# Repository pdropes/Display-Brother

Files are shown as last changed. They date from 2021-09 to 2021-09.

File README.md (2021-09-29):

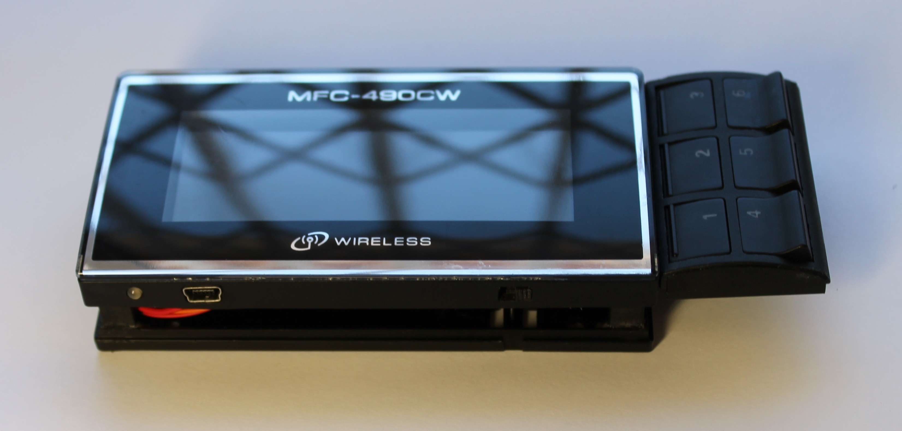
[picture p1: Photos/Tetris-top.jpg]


# Display-Brother
Reverse engineering a display

I had a brother printer, a color display and such, with a dismal flatcable communicating at a speed of +-4MHz... without a logic analyzer, it would be impossible to do anything to understand the protocol. Information on the net is non-existent, however the service manual is always better than nothing.
I got an AL for 200 bucks for this, I still use it.

It took me a long time to make this game, I didn't use any library and the code (Bascom AVR) is in a single file.
With the gathering of information, readings and tests, the files grew, ending up in 3,183 files.
After programming, 33 versions were needed, and now there are no apparent bugs.

These were the reasons why I haven't shared the code and other information yet (besides my pc having crashed), if I'm going to share something, I'd like it to make sense for those who are going to read it, and not a bunch of files.

Both the resolution and the quality reproduced on the display are low, however sufficient for many applications.

I started with an M8515 because it has more IOs, making it possible to connect to a PC's parallel port to exchange information.
All 120ohm resistors were soldered just as a precaution in the tests, there being no need to keep them after confirmation of communications.

The number of connections was reduced to a minimum, sometimes joining some, it was possible to connect it to a common m328 leaving 2 ADC pins available.

A lot of information about commercial displays and mobile phones circulates on the internet, I appreciate whoever recovers unused equipment for other purposes, this was one more challenge and a learning curve, since the expenses far exceed the value of a commercial display.

*Stay creative

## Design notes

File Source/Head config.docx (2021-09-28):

-Resumo das operações sugestivas a serem implementadas antes do envio de uma imagem-

'Contraste (valor de 0..3)

If Cnt = 85 Then

B2 = 0

End If

'Inversão de escrita (esquerda para direita)

If Cnt = 29 Then

B1 = 46

B2 = 34

End If

'Cores invertidas (apenas ao escrever)

If Cnt = 29 Then

B1 = 30

B2 = 18

End If

'Escreve apenas na selecção (valor de 0..175):

'Inicio da secção

If Cnt = 94 Then

B1 = 0

B2 = 0

End If

'Final da secção

If Cnt = 96 Then

B1 = 175

B2 = 175

End If

*_Cnt é um contador da posição da matriz de dados

*_B1 quadro 1

*_B2 quadro 2

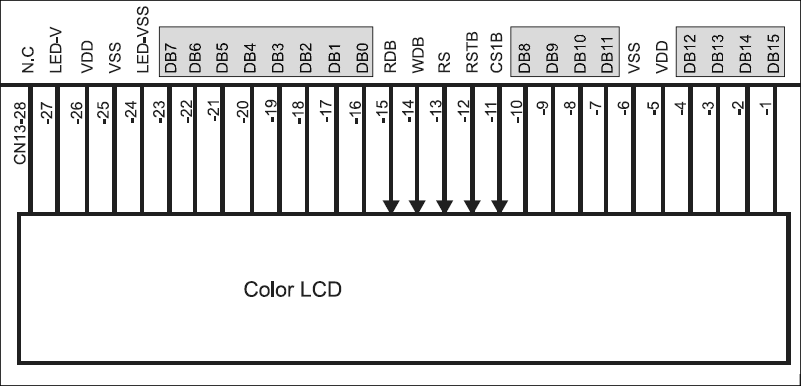
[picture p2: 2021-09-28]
Infos/Pinout Display 990CW.png

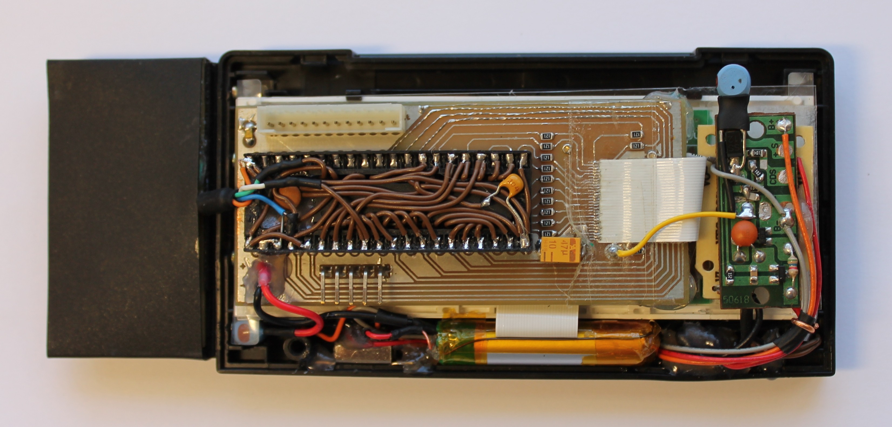
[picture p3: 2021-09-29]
Photos/Tetris-bottom.jpg

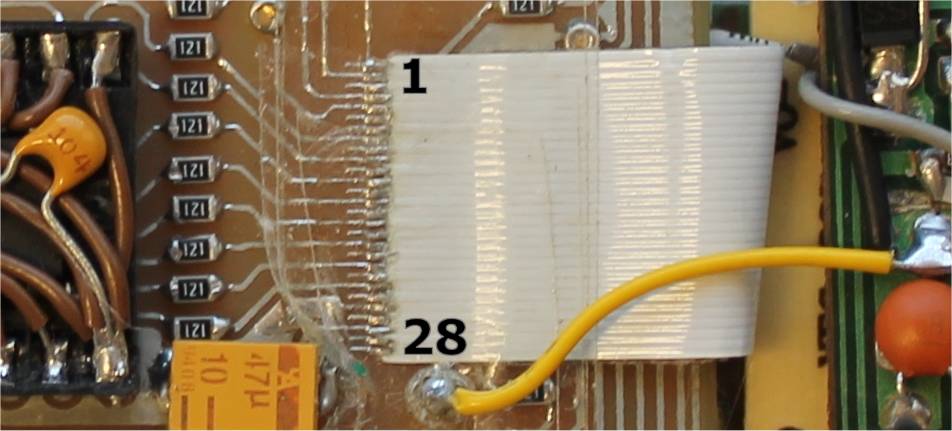
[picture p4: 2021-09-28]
Infos/Display Brother - orientação.jpg

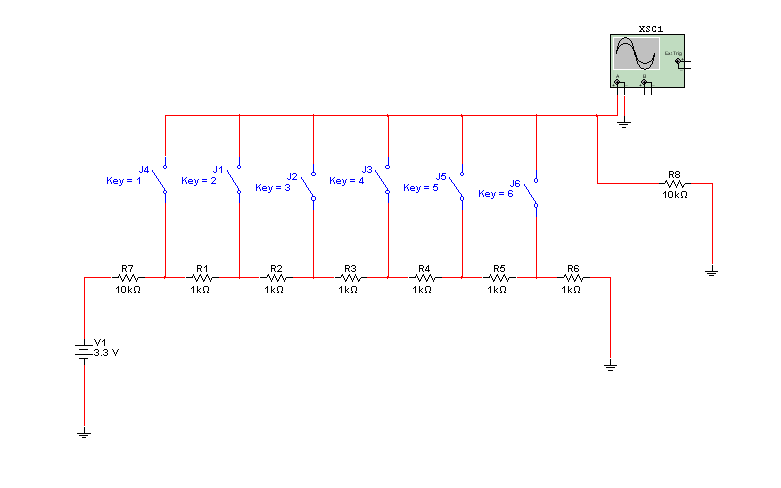
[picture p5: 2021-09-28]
Layout/switchs 6P 1Vmax.png

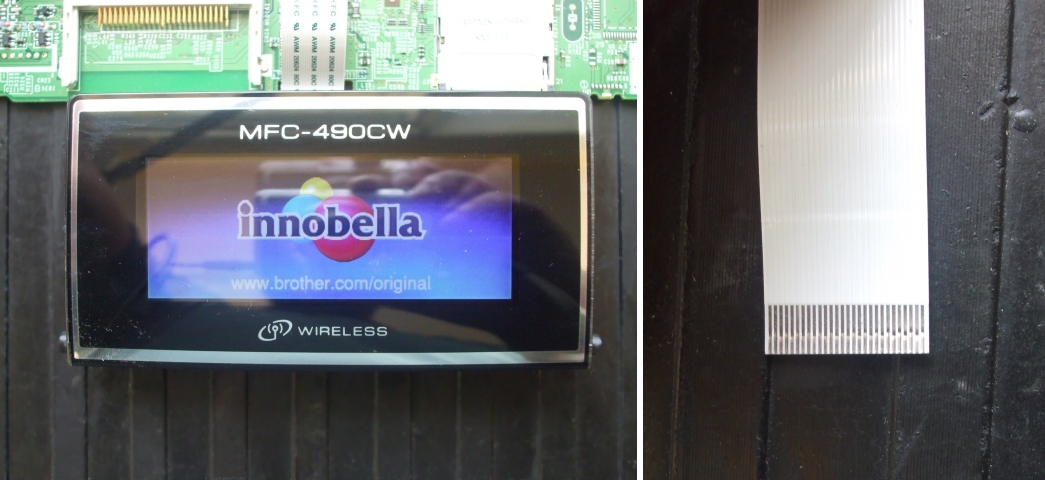
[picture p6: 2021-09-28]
Infos/Brother display + cable.jpg

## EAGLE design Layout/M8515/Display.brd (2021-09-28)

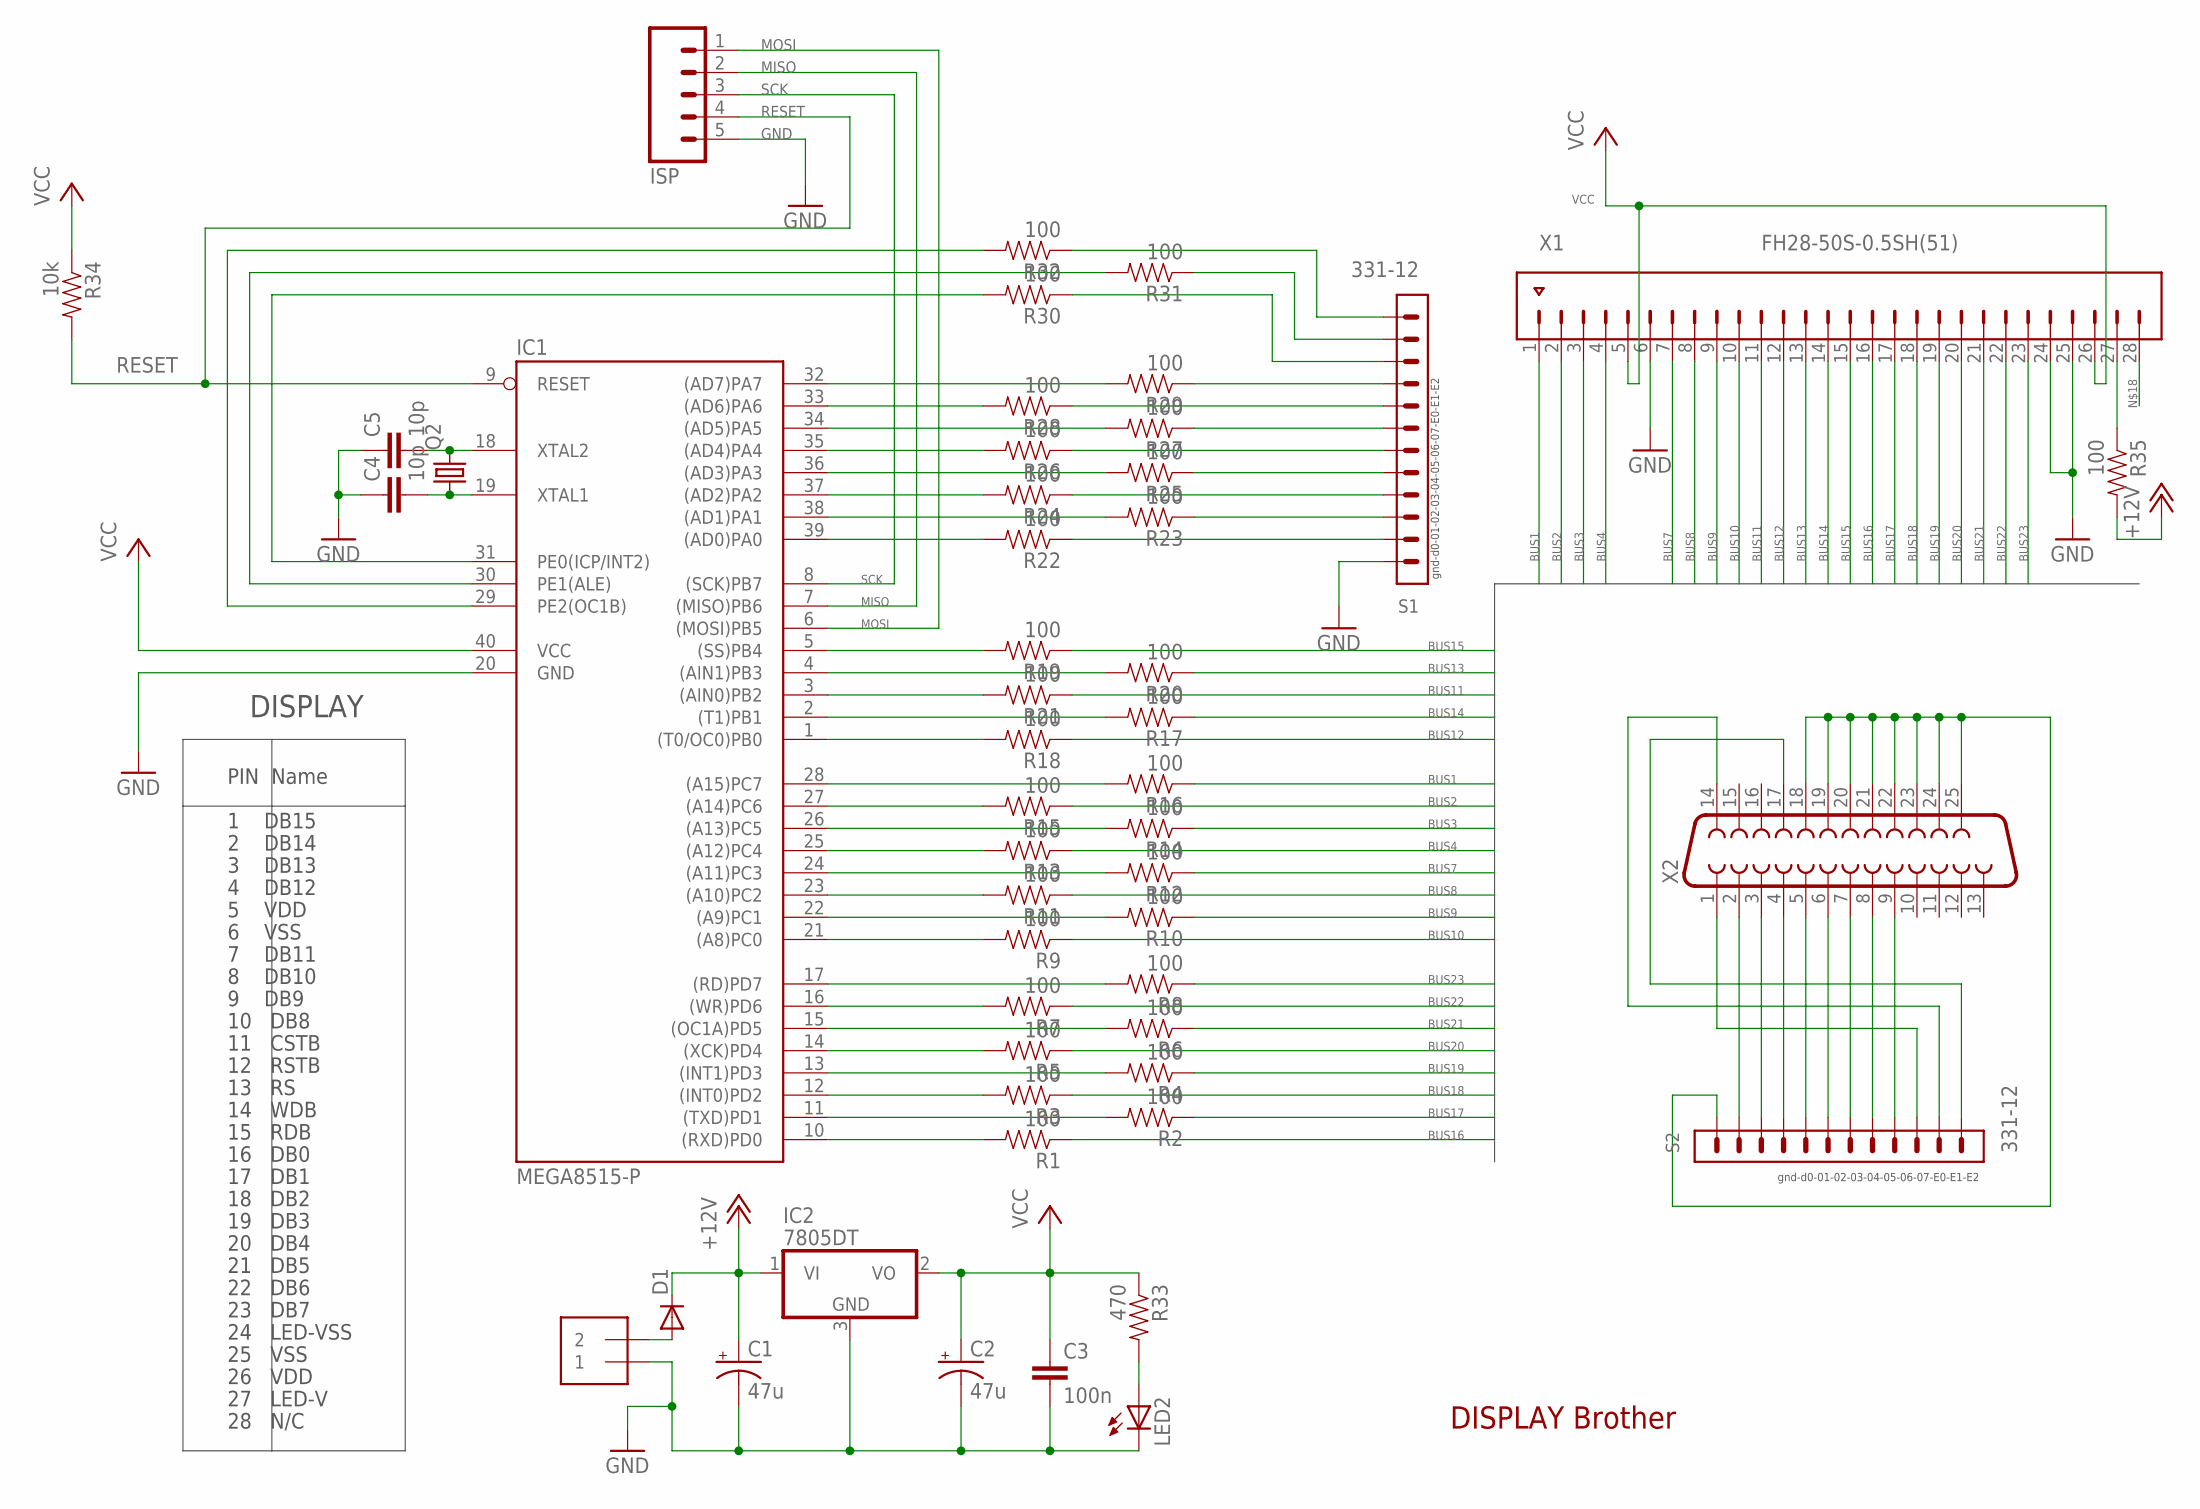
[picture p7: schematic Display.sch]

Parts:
C1, C2: 47u; EIA3216-KIT
C3: 100n; 0805
C4, C5: 10p; 0805
D1: DIODESMA-KIT; SMA-DIODE-KIT
IC1: MEGA8515-P; DIL40
IC2: 7805DT; TO252
ISP: M05PTH_LONGPADS; 1X05_LONGPADS
J2: 1X2-3.5MM
LED2: LED3MM
Q2: CRYSTALHC49UP; HC49UP
R1, R2, R3, R4, R5, R6, R7, R8, R9, R10, R11, R12, R13, R14, R15, R16, R17, R18, R19, R20, R21, R22, R23, R24, R25, R26, R27, R28, R29, R30, R31, R32, R35: 100; 0805
R33: 470; 0805
R34: 10k; 0805
S1, S2: 331-12
X1: FH28-50S-0.5SH(51)
X2: F25D

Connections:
+12V: C1.A (+), D1.C, IC2.1 (VI), R35.2
BUS1: R16.1, X1.1
BUS2: R15.1, X1.2
BUS3: R14.1, X1.3
BUS4: R13.1, X1.4
BUS7: R12.1, X1.7
BUS8: R11.1, X1.8
BUS9: R10.1, X1.9
BUS10: R9.1, X1.10
BUS11: R21.1, X1.11
BUS12: R18.1, X1.12
BUS13: R20.1, X1.13
BUS14: R17.1, X1.14
BUS15: R19.1, X1.15
BUS16: R1.1, X1.16
BUS17: R2.1, X1.17
BUS18: R3.1, X1.18
BUS19: R4.1, X1.19
BUS20: R5.1, X1.20
BUS21: R6.1, X1.21
BUS22: R7.1, X1.22
BUS23: R8.1, X1.23
BUS-E0: IC1.31 (PE0(ICP/INT2)), R30.2
BUS-E1: IC1.30 (PE1(ALE)), R31.2
BUS-E2: IC1.29 (PE2(OC1B)), R32.2
GND: C1.C (-), C2.C (-), C3.2, C4.1, C5.1, IC1.20 (GND), IC2.3 (GND), ISP.5, J2.1, LED2.K (C), S1.1, X1.6, X1.24, X1.25
GND3: S2.1, X2.18, X2.19, X2.20, X2.21, X2.22, X2.23, X2.24, X2.25
MISO: IC1.7 ((MISO)PB6), ISP.2
MOSI: IC1.6 ((MOSI)PB5), ISP.1
unnamed: LED2.A, R33.2
unnamed: IC1.10 ((RXD)PD0), R1.2
unnamed: IC1.12 ((INT0)PD2), R3.2
unnamed: IC1.14 ((XCK)PD4), R5.2
unnamed: IC1.16 ((WR)PD6), R7.2
unnamed: IC1.17 ((RD)PD7), R8.2
unnamed: IC1.15 ((OC1A)PD5), R6.2
unnamed: IC1.13 ((INT1)PD3), R4.2
unnamed: IC1.11 ((TXD)PD1), R2.2
unnamed: IC1.28 ((A15)PC7), R16.2
unnamed: IC1.27 ((A14)PC6), R15.2
unnamed: IC1.25 ((A12)PC4), R13.2
unnamed: IC1.23 ((A10)PC2), R11.2
unnamed: IC1.21 ((A8)PC0), R9.2
unnamed: IC1.22 ((A9)PC1), R10.2
unnamed: IC1.24 ((A11)PC3), R12.2
unnamed: IC1.26 ((A13)PC5), R14.2
unnamed: IC1.3 ((AIN0)PB2), R21.2
unnamed: IC1.1 ((T0/OC0)PB0), R18.2
unnamed: IC1.4 ((AIN1)PB3), R20.2
unnamed: C4.2, IC1.19 (XTAL1), Q2.1
unnamed: S2.2, X2.2
unnamed: S2.3, X2.3
unnamed: IC1.2 ((T1)PB1), R17.2
unnamed: S2.4, X2.4
unnamed: S2.5, X2.5
unnamed: S2.6, X2.6
unnamed: S2.7, X2.7
unnamed: IC1.5 ((SS)PB4), R19.2
unnamed: R22.1, S1.2
unnamed: IC1.38 ((AD1)PA1), R23.2
unnamed: R24.1, S1.4
unnamed: S2.8, X2.8
unnamed: IC1.36 ((AD3)PA3), R25.2
unnamed: S2.10, X2.1
unnamed: R26.1, S1.6
unnamed: S2.11, X2.14
unnamed: IC1.34 ((AD5)PA5), R27.2
unnamed: R28.1, S1.8
unnamed: IC1.32 ((AD7)PA7), R29.2
unnamed: IC1.39 ((AD0)PA0), R22.2
unnamed: R23.1, S1.3
unnamed: IC1.37 ((AD2)PA2), R24.2
unnamed: R25.1, S1.5
unnamed: IC1.35 ((AD4)PA4), R26.2
unnamed: R27.1, S1.7
unnamed: IC1.33 ((AD6)PA6), R28.2
unnamed: R29.1, S1.9
unnamed: R30.1, S1.10
unnamed: R32.1, S1.12
unnamed: R31.1, S1.11
unnamed: D1.A, J2.2
unnamed: S2.9, X2.9
unnamed: C5.2, IC1.18 (XTAL2), Q2.2
unnamed: S2.12, X2.17
unnamed: R35.1, X1.27
RESET: IC1.9 (RESET), ISP.4, R34.2
SCK: IC1.8 ((SCK)PB7), ISP.3
VCC: C2.A (+), C3.1, IC1.40 (VCC), IC2.2 (VO), R33.1, R34.1, X1.5, X1.26

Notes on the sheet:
PIN Name
23 DB7
24 LED-VSS
25 VSS
26 VDD
14 WDB
2 DB14
16 DB0
17 DB1
18 DB2
19 DB3
3 DB13
4 DB12
5 VDD
6 VSS
11 CSTB
12 RSTB
13 RS
15 RDB
27 LED-V
1 DB15
7 DB11
8 DB10
9 DB9
10 DB8
28 N/C
22 DB6
21 DB5
20 DB4
DISPLAY
gnd-d0-01-02-03-04-05-06-07-E0-E1-E2
DISPLAY Brother

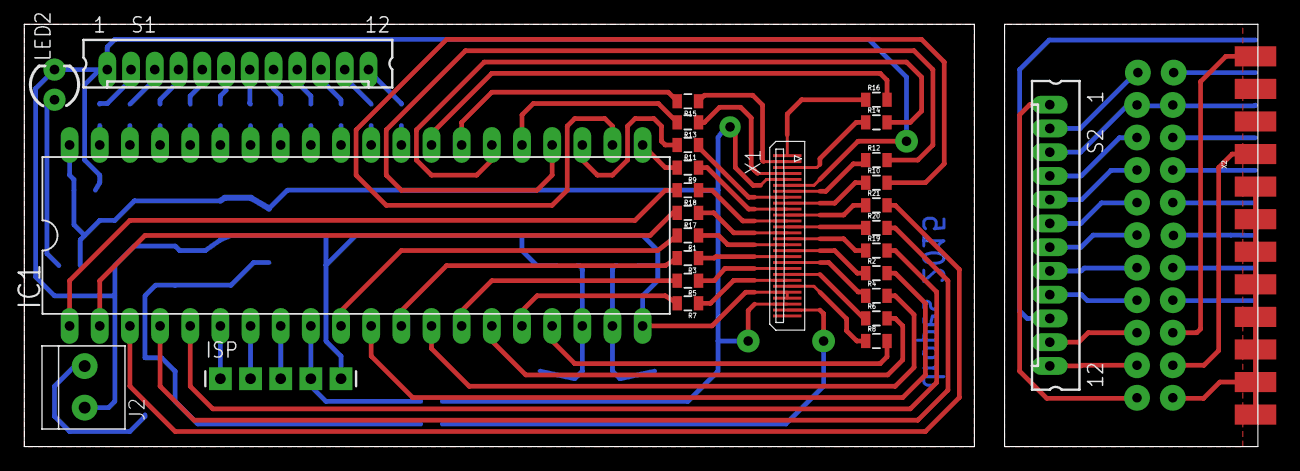
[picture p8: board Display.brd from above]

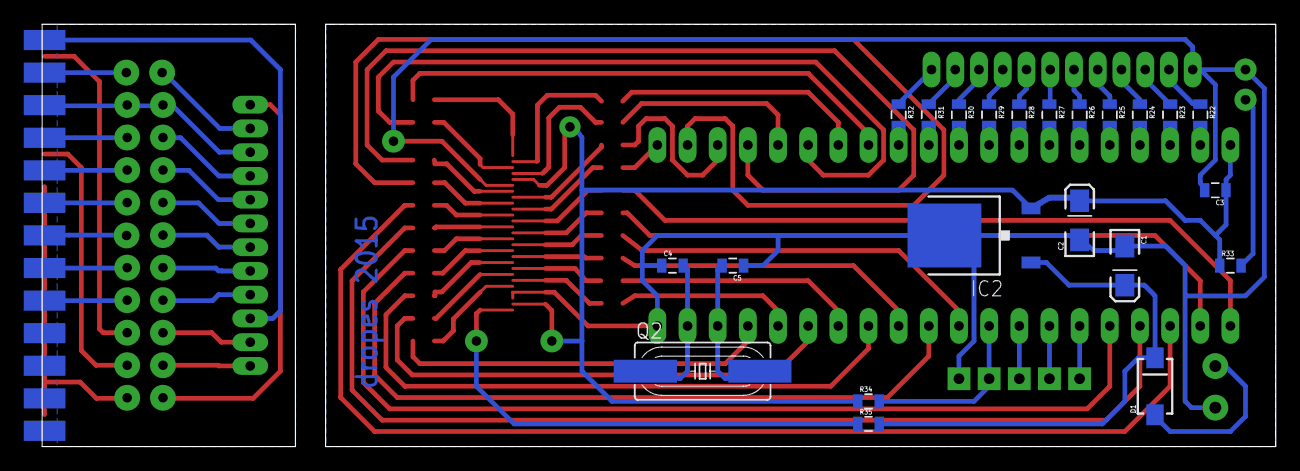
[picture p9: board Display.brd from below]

Board: 2 copper layers, 103.9 x 35.6 mm, 51 parts (22 on the bottom side), 88 nets.

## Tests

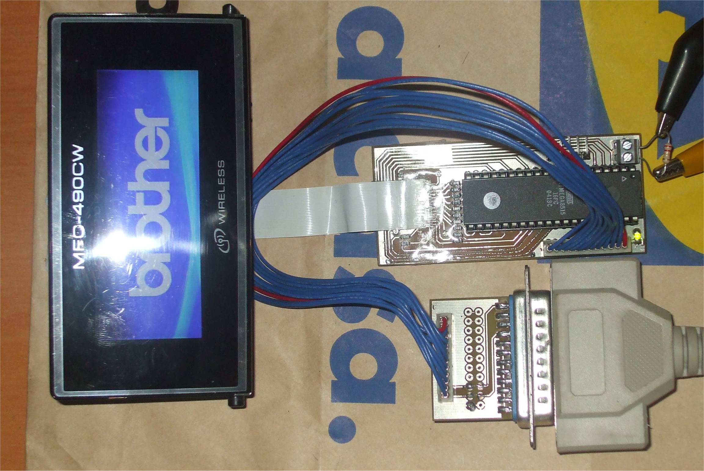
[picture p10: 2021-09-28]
Photos/Em testes no PC.jpg

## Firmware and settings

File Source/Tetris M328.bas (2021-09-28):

'02 OUTUBRO 2016    Bascom V2.0.8.1  (81% FLASH)
$regfile = "m328pdef.dat"
$crystal = 16000000

$hwstack = 42
$swstack = 20
$framesize = 50



'LCD Byte1 <=> mantém-se 328P PortD
Ddrd = &HFF
Config Portd = Output
Portd = &HFF

'LCD Byte2 <=> (0..5)lsb
'Ddrb = &B111111
Ddrb = &HFF
Config Portb = Output
Portb = &HFF

'LCD Byte2 + CRTL <=> Byte2(0..1)msb + CTRL(2..4)
'Ddrc = &B011111
Ddrc = &B011111
Config Portc = Output
Portc = &B111111

'The prescaler divides the internal clock by 2,4,8,16,32,64 or 128
Config Adc = Single , Prescaler = 16 , Reference = Internal 'Keyboard
Enable Adc

Dim Send_b As Byte
Dim Send_c As Byte
Dim Send_c1 As Byte
Dim Send_c2 As Byte
Dim Crt As Byte



Const Paper = 99                                            'cor fora da moldura
Const Back = 41                                             'cor dentro da moldura
Const Info_back = 0                                         'cor de fundo da informação
Const Text_back = 80

Dim Cnt As Integer

Dim Byte_ As Byte
Dim Integer_ As Integer

Dim Sw As Byte

Dim X As Integer
Dim Y As Integer
Dim X2 As Byte
Dim Y2 As Byte

Dim B1 As Byte
Dim B2 As Byte
Dim B_crt As Byte

Dim K As Byte
Dim Kb(2) As Byte

'Peças
Dim Sprite(16) As Byte                                      'peça escolhida
Dim Sprite_tmp(16) As Byte                                  'auxilia na rotação
Dim Sprite_ok(16) As Byte                                   'grava a última peça boa
Dim Id As Byte                                              'ID da peça a tratar
Dim Id_next As Byte
Dim Cor As Byte                                             'manupulação de cores

'Matriz
Dim Colide As Byte                                          'detecta colisões
Dim Matrix(230) As Byte                                     'quadro virtual 10x20 (+ 10 * 20)
Dim Matrix_sector(40) As Byte                               'testa movimentos e colisões antes de passar para ok
Dim Matrix_sector_ok(40) As Byte                            'backup para visualizar e gravar no final
Dim Fx_sprite(12) As Byte                                   'efeito 3D nas peças
Dim Ok_sector_x As Byte                                     'memória da última boa posição
Dim Ok_sector_y As Byte                                     ' //

'Matrix = 12 x (10 x 20)
'Sector = 10 x 4
'Sprite = 4 x 4

Dim Mx As Integer                                           'posição X do matrix ou sector
Dim My As Integer                                           'posição Y do matrix ou sector
Dim Mz As Integer                                           'posição em array do matrix ou sector

Dim Go_x As Integer                                         'memória X da posição boa
Dim Go_y As Byte                                            'memória Y da posição boa

Dim Rep As Byte
Dim Free As Byte
Dim Delay_ As Integer
Dim Moviment As Byte

Dim Level As Byte
Dim Level_inc As Byte
Dim Point As Long
Dim Point_calc As Long
Dim Long_ As Long

Dim Analog As Integer

Declare Sub Header
Declare Sub Header_y(byval B1_start As Byte , Byval B1_end As Byte , Byval B2_start As Byte , Byval B2_end As Byte )
Declare Sub Ending
Declare Sub Background_screen
Declare Sub Get_sprite(byval Spr As Byte)
Declare Sub Rotate_sprite(byval Id1 As Byte)
Declare Sub Print_matrix_line(byval Array_ As Byte , Byval Line_n As Byte)
Declare Sub Clock
Declare Sub Get_matrix_sector(byval Line_ As Byte)
Declare Sub Sprite_to_sector_colide
Declare Sub Show_matrix_lines(byval Y_pos As Byte)
Declare Sub Copy_ok_to_matrix
Declare Sub Check_lines

Declare Sub Show_logo
Declare Sub Game_over
Declare Sub Show_next
Declare Sub Text(byval Char_pos As Byte , Byval Cor_back As Byte)
Declare Sub Space_(byval Esp_x As Byte , Byval Esp_y As Byte)

Declare Sub Info(byval Numeros As Integer)
Declare Sub Ranking



'Matrix
'0123456789
'XXXXXXXXXX 0
'XXXXXXXXXX 1
'XXXXXXXXXX 2
'XXXXXXXXXX 3
'XXXXXXXXXX 4
'XXXXXXXXXX 5
'XXXXXXXXXX 6
'XXXXXXXXXX 7
'XXXXXXXXXX 8
'XXXXXXXXXX 9
'XXXXXXXXXX 10
'XXXXXXXXXX 11
'XXXXXXXXXX 12
'XXXXXXXXXX 13
'XXXXXXXXXX 14
'XXXXXXXXXX 15
'XXXXXXXXXX 16
'XXXXXXXXXX 17
'XXXXXXXXXX 18
'XXXXXXXXXX 19

'RGB RRRBBGGG
'X=0..131(x2=352) Y=0..176

  'Apaga toda a matriz
For K = 1 To 200
    Matrix(k) = Back
Next K
    'Coloca uma fila virtual em baixo e sobram duas a 0
For K = 201 To 210
    Matrix(k) = 88
Next K

    'Grava a sequência de cor FX em FX_sprite
Restore Fx_sprite_table
For K = 1 To 12
    Read Byte_
    Fx_sprite(k) = Byte_
Next K


Call Show_logo
Portc.5 = 0
While Analog = 0
    Analog = Getadc(5)
    Id_next = Rnd(7)
Wend


Call Background_screen


'----------------------------MAIN-------------------------------
Do

   '0..6
    Id = Id_next                                             'copia next para a peça presente
    Id_next = Rnd(7)                                         'gera aleatório da peça next
    Call Get_sprite(id_next)                                 'coloca a peça next em array
    Call Show_next                                           'apresenta a peça next
    Call Get_sprite(id)                                      'coloca a peça presente em array


   'posição horizontal a colocar a peça
    Go_x = 4

'Moviment:
'0 = livre
'1 = rotação
'2 = peça para baixo
'3,4 = deslocação lateral
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

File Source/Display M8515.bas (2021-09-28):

'7 AGOSTO 2016
'Este programa é apenas para visualisar os comandos de acesso ao display (versão simplificada)

'Resumo aqui o seu controle:
'Head - Deve sempre ser iniciado com com esta sequência
'           Ao se enviar a sequência, cada valor é enviado à respectiva porta, nomeados B1, B2 e B_crt sucessivamente
'           Dentro destes dados, existem alguns que podem ser modificados para outros fins, descrito mais adiante
'           O display está dividiso tem duas secções, B1 e B2, ou esquerda e direita
'           B1 e B2 são escritos em simultâneo ou individualmente
'Foot -  Sequência a ser enviada no final de cada escrita, seja escrita parcial ou ecrân completo

'Desconheço por completo o protocolo usado no inicio e no fim, foi por tentativa que alterei cada valor para encontrar resultados.


$regfile = "m8515.dat"
$crystal = 8000000

$hwstack = 32                                               ' default use 32 for the hardware stack
$swstack = 10                                               ' default use 10 for the SW stack
$framesize = 40                                             ' default use 40 for the frame space


'LCD Byte1
Ddrd = &HFF
Config Portd = Output
Portd = &H00

'LCD Byte2
Ddrc = &HFF
Config Portc = Output
Portc = &H00

'LCD CTRL
Ddrb = &HFF
Config Portb = Output
Portb = &H00

Dim Cnt As Integer
Dim X , Y As Integer

Dim B1 , B2 , B_crt As Byte

Declare Sub Header
Declare Sub Ending

Call Header
'2 X(132 X 176)
'Fill RED RRRBBGGG =111 00 000
For X = 0 To 131
    For Y = 0 To 175
        B1 = &B11100000
        B2 = &B11100000

        'Regist + Clock
        Portd = B1
        Portc = B2
        Portb = 25

        Portd = B1
        Portc = B2
        Portb = 31

        Portd = B1
        Portc = B2
        Portb = 25

        Portd = B1
        Portc = B2
        Portb = 31
    Next Y
Next X

Call Ending

Do
Loop

'---------------------------------------------------------------------
'----------------------------Header---------------------------------
Sub Header
'Quadro 1 = DB8..DB15
'Quadro 2 = DB0..DB7

'Operações sugestivas a serem implementadas antes do envio de uma imagem
'Estas operações também podem ser realisadas alterando directamente os valores de "DATA Head"
'Quando se quer escrever apenas num quadro, o inicio aqui declarado deve ser igual ao fnal (fora do limite)
    Restore Head
    'Apagar os casos não usados:
    For Cnt = 0 To 103
        Read B1
        Read B2
        Read B_crt

        Select Case Cnt
            Case 29 :
            'Inversão de escrita (esquerda para direita)
                B1 = 46
                B2 = 34
                'B1=22 & B2=26 = cores invertidas
                'B1=46 & B2=34 X invertido (usado neste exemplo)
                'B1=30 & B2=18 = cores e X invertido
            Case 85:
            'Contraste (valor de 0..3)
                B2 = 0
            Case 94:
             'Começo da escrita  (200 para escrever apenas num quadro)
                B1 = 0
                B2 = 0
            Case 96:
             'Final da escrita        (200 para escrever apenas num quadro)
                B1 = 175
                B2 = 175

            'Resumo de todas as alterações com resultados:
            '28, 29 res bad
            '32, 33, 34, 35,  só em cima, baixo com risco
            '36, 37 / 84, 85, 86, 87 ambos com risco
            '59, 60 blank
            '61, 62 cima estranho em branco
            '71, 72 troca de quadros cores com problemas
            '85 contraste
            '93, 94 risco na separação
            '94 largura de cada quadro em baixo
            '96 largura de cada quadro em cima
            '99 / 100 escreve no último Y
            '102 risco na separação
            '103 apaga e bloqueia
        End Select
        Portd = B1
        Portc = B2
        Portb = B_crt
    Next Cnt
End Sub
'---------------------------------------------------------------------
'----------------------------Ending----------------------------------
Sub Ending
    Restore Foot
    For Cnt = 0 To 9
        Read B1
        Read B2
        Read B_crt
        Portd = B1
        Portc = B2
        Portb = B_crt
    Next Cnt
End Sub

End
'---------------------------------------------------------------------
'----------------------------DATA-----------------------------------
'---------------------------------------------------------------------

Head:                                                       'B1, B2, B_crt, B1, B2, B_crt...
    Data &H00 , &H00 , &H1E , &H00 , &H00 , &H1F , &H00 , &H00 , &H17 , &H7F , &H7F , &H11 , &H7F , &H7F , &H17 , &H73 , &H73 , &H11 , &H73 , &H73 , &H17 , &H7F , &H7F , &H11 , &H7F , &H7F
    Data &H17 , &H77 , &H77 , &H11 , &H77 , &H77 , &H17 , &H77 , &H77 , &H1F , &H77 , &H77 , &H17 , &H2C , &H2C , &H11 , &H2C , &H2C , &H17 , &H2C , &H2C , &H1F , &HF9 , &HF9 , &H11 , &HF9
    Data &HF9 , &H17 , &H00 , &H00 , &H11 , &H00 , &H00 , &H17 , &H00 , &H00 , &H11 , &H00 , &H00 , &H17 , &HC0 , &HC0 , &H11 , &HC0 , &HC0 , &H17 , &H40 , &H40 , &H11 , &H40 , &H40 , &H17
    Data &H40 , &H40 , &H1F , &H40 , &H40 , &H17 , &H06 , &H0A , &H11 , &H06 , &H0A , &H17 , &H18 , &H18 , &H11 , &H18 , &H18 , &H17 , &H00 , &H38 , &H11 , &H00 , &H38 , &H17 , &H02 , &H02
    Data &H11 , &H02 , &H02 , &H17 , &H02 , &H01 , &H11 , &H02 , &H01 , &H17 , &H02 , &H01 , &H1F , &H24 , &H24 , &H11 , &H24 , &H24 , &H17 , &H33 , &H33 , &H11 , &H33 , &H33 , &H17 , &H20
    Data &H20 , &H11 , &H20 , &H20 , &H17 , &H01 , &H01 , &H11 , &H01 , &H01 , &H17 , &H01 , &H01 , &H1F , &H22 , &H22 , &H11 , &H22 , &H22 , &H17 , &H22 , &H22 , &H11 , &H22 , &H22 , &H17
    Data &H36 , &H36 , &H11 , &H36 , &H36 , &H17 , &H20 , &H20 , &H11 , &H20 , &H20 , &H17 , &H2A , &H2A , &H11 , &H2A , &H2A , &H17 , &H2A , &H2A , &H1F , &HA9 , &HA9 , &H11 , &HA9 , &HA9
    Data &H17 , &H26 , &H26 , &H11 , &H26 , &H26 , &H17 , &H00 , &H10 , &H11 , &H00 , &H10 , &H17 , &H00 , &H10 , &H1F , &H00 , &H10 , &H17 , &H10 , &H10 , &H11 , &H10 , &H10 , &H17 , &H10
    Data &H10 , &H1F , &H10 , &H10 , &H17 , &H33 , &H31 , &H11 , &H33 , &H31 , &H17 , &H34 , &H34 , &H11 , &H34 , &H34 , &H17 , &H34 , &H34 , &H1F , &H13 , &H13 , &H11 , &H13 , &H13 , &H17
    Data &H30 , &H30 , &H11 , &H30 , &H30 , &H17 , &H12 , &H12 , &H11 , &H12 , &H12 , &H17 , &H28 , &H28 , &H11 , &H28 , &H28 , &H17 , &H00 , &H00 , &H11 , &H00 , &H00 , &H17 , &H32 , &H32
    Data &H11 , &H32 , &H32 , &H17 , &H02 , &H02 , &H11 , &H02 , &H02 , &H17 , &H02 , &H02 , &H1F , &H42 , &H42 , &H11 , &H42 , &H42 , &H17 , &H00 , &H00 , &H11 , &H00 , &H00 , &H17 , &HAF
    Data &HAF , &H11 , &HAF , &HAF , &H17 , &H43 , &H43 , &H11 , &H43 , &H43 , &H17 , &H00 , &H00 , &H11 , &H00 , &H00 , &H17 , &H83 , &H83 , &H11 , &H83 , &H83 , &H17 , &H83 , &H83 , &H1F
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

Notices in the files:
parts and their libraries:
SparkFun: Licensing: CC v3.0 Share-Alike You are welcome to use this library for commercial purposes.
